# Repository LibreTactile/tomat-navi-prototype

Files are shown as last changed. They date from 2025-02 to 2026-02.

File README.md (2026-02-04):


# tomat-navi-prototype
Prototype for Touch Matrix Assistive Technology Navigator (TOMAT) 

# Overview
“Touch Matrix Assistive Technology Navigator” (tomat navigator) is an affordable, open-source assistive technology that uses AI and tactile technologies to make it easier and more natural for visually impaired users to navigate the internet. It works as a companion device for screen readers, providing an interactive non-visual representation of a webpage through audio-tactile feedback. It works as a companion device for screen readers, providing an interactive non-visual representation of a webpage through audio-tactile feedback. It was codesigned with and for visually impaired screen reader users. 

## TOMAT Light (Smartphone Version)
A software-only alternative called **TOMAT Light** is available as a Progressive Web App (PWA). It uses a smartphone's touchscreen and vibration motor to simulate the hardware interface.
- **Repository**: [tomat-light-pwa](https://github.com/LibreTactile/tomat-light-pwa)
- **Design**: Leveraging WebRTC for peer-to-peer connection with the browser extension.

# Repo structure
- docs
    - [prototype description](/docs/1%20prototype%20description.md)
        - [design document draft](/docs/2%20design%20doc.md)
    - [use guide](/docs/3%20use%20guide.md)
    - [build guide](/docs/4%20build-guide.md) (pending)

- source files
    - hardware (alternative use the tomat-[light-launcher](https://github.com/LibreTactile/light-launcher))
      - 3d printer files (freeCAD 3d models) 
      - pico firmware
      - bill of materials (for building 5 prototypes)
    - software
      - chrome extension
    - external repositories
      - [tomat-light-pwa](https://github.com/LibreTactile/tomat-light-pwa) (TOMAT Light Smartphone Interface)

# Intellectual Property Strategy

## Commitment to Open Innovation with Strategic Protection

Our team remains commited to our mission to advance assistive technology through open collaboration. To balance innovation protection with community growth, we've implemented a **phased intellectual property strategy** guided by [Axelys](https://www.axelys.ca/en/), Quebec's nonprofit expert in research commercialization and technology transfer.

### Current Licensing Framework (Phase 1)


**Temporary License:** Creative Commons Attribution-NonCommercial-ShareAlike 4.0 International  

**Key Provisions:**
- ✅ **Permitted:**  
  - Academic research & non-commercial use  
  - Prototyping & personal adaptation  
  - Educational implementations  

- ⚠️ **Restricted Without Written Consent:**  
  - Commercial distribution or integration  
  - Forking for proprietary development  
  - Patent filings derived from this work  

**Full License Text:** [LICENSE](/LICENSE)

> External contributions will require CLA to facilitate relicensing. 

### Transition Roadmap to Full Open Source (Phase 2)

**Target License:** CERN-OHL-P v2 or Apache 2.0 (or equivalent)  

**Transition Triggers:**  
1. Completion of Axelys' technology assessment (AXE-0431: completed on summer 2024)
2. Establishment of sustainable funding model (ongoing)

**Declaration of intention:** All core contributors have declared their intention to open-source release through our [Open Source Release Agreement](/docs/open-source%20release%20agreement.pdf).

### Why This Approach?

1. **Protection During Development**  
   Prevents patent trolling while enabling academic collaboration during critical R&D phases.

2. **Sustainable Commercialization**  
   Allows time to establish ethical commercialization partnerships that will fund ongoing development.

3. **Community Safeguards**  
   Ensures derivative works remain accessible to visually impaired users through copyleft provisions.

### How This Affects You

**Researchers & Educators:**  
- Full access to current implementations  
- Ability to publish papers/case studies (with attribution)  
- Pathway for collaborative grants  

**Developers:**  
- Protected right to fork upon full open-source release  
- Clear timeline for commercial participation  

**End Users:**  
- Guaranteed perpetual access to assistive innovations  
- Protection from proprietary lock-in  

*This strategy follows OSI's [Delayed Open Source Publication Guidelines](https://opensource.org/delayed-open-source-publication)*

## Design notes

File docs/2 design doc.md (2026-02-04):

# **TOMAT Navigator Design Document**  
**A Multimodal, Non-Linear Web Navigation System for Visually Impaired Users**  

version: 0.1,draft for prototype for codesing and usability evaluation  
author: Juan Nino  
date: 24 February 2025

## **Context**  

>[Related publication](https://digitalcommons.lindenwood.edu/faculty-research-papers/714/)  
Nino, J., Ochoa, S., Kiss, J., Edwards, G., Morales, E., Hutson, J., ... & Wittich, W. (2024). Assistive Technologies for Internet Navigation: A Review of Screen Reader Solutions for the Blind and Visually Impaired. International Journal of Recent Engineering Science, 11(6).

The **TOMAT Navigator** is a hardware and software **assistive human-computer interface** within the **LibreTactile** ecosystem (vision: *touching ideas*), designed to empower visually impaired users to navigate the internet through **nonlinear, multimodal interaction**. Traditional screen readers present content sequentially, forcing users to reconstruct webpage structure mentally. TOMAT addresses this by generating multimodal **interactable models** of webpages, enabling users to explore relationships between elements, adjust detail granularity, and interact contextually via audio-tactile feedback and gesture-based inputs. Algorithms and AI systems generate interactive webpage models from the DOM, representing structural (hierarchical), visuospatial, and/or semantic relationships. Alternatively, models for popular pages could be shared by community of users and developers. 

TOMAT Navigator transforms linear screen reader experiences into **multiscale, nonlinear navigation**. It dynamically models webpage structure as a **collapsible tree**, allowing users to "zoom in & out" between high-level overviews and granular details. Key innovations include:  
- **Multiperspective Modeling**: Represent webpages as information graphs that can be organized into multiple tree hierarchies, such as tables of contents. These hierarchies are shaped by the type of nonlinear information used to build them, including semantic ontologies, hierarchical relationships, or visuospatial layouts.
- **Multiscale Rendering**: Enable interaction with content through the generated table of contents, offering multiple levels of abstraction (e.g., from section summaries to full text).
- **AI Assistant**: Automatically annotate pages, predict navigation paths, and fix accessibility issues while allowing manual user control.  
- **Contextual Interactions**: Intuitive touch/button interactions to switch modes, adjust detail, or trigger actions.  

**Hardware Overview**:  
The TOMAT hardware module is a portable, 3D-printed tactile interface featuring:  
- A **4x4 vibratory matrix** to represent webpage elements through tactile "table of contents".  
- **Gesture-enabled buttons** (8 total) supporting taps, holds, and combos for contextual actions.  
- **Raspberry Pi Pico microcontroller** for real-time communication with the software module via USB/WiFi.  
- Ergonomic design (12cm x 8cm) with rounded edges for comfortable handheld use.  

---

## **Core Features**  

### **1. Multiperspective Modeling**  
- **Dynamic Graph/Tree Generation**: Extract relationships between DOM elements (headings, links, tables) and represent them as interactive tree hierarchies (e.g., tables of contents).  
- **Custom Ontologies**: Users or communities define semantic relationships (e.g., `#workflow`, `#socialnetworking`) to tailor generated webpage models.  

### **2. Multiscale Rendering (Levels of Detail)**  
- **Granularity Control**:  
  - **Zoom In/Out**: Adjust detail with `+/-` buttons (e.g., show all subheadings vs. top-level headings).  
  - **Auto-Summarization**: AI generates concise section summaries, enabling quick overviews. User can then manually dive deeper into the details of a section of interest.  
- **Adaptive Focus**:  
  - **Element Exploration Mode**: Interact with complex elements (e.g., tables, lists) using the full tactile matrix.  
  - **Type Grouping**: Group elements by type (e.g., links in one column) for focused navigation.  

### **3. AI Assistant & Automation**  
- **Pre-Annotation**:  
  - AI labels elements (e.g., "navigation menu," "article body") where human annotations are missing.  
  - Override AI suggestions manually (e.g., relabel, hide elements).  
- **Task Automation**:  
  - **Smart Navigation**: Predict frequent paths (e.g., "Skip to main content") based on user habits.  
  - **Accessibility Fixes**: Auto-correct ARIA roles or missing alt-text, pending user approval.  
- **Interruptible Workflow**: Pause/reset AI actions instantly via gestures (e.g., double-tap to halt automation).  

### **4. Contextual Interaction & Gestures**  
- **Gesture Library**:  
  | **Button/Gesture**       | **Action**                                  |  
  |---------------------------|--------------------------------------------|  
  | `Single Tap (T)`          | Read element description.                  |  
  | `Double Tap (TT)`         | Jump to element.                           |  
  | `Press & Hold (PH)`       | Save to favorites.                         |  
  | `Tap + Hold (TPH)`        | Trigger AI summary or custom script.       |  
- **Mode Switching**:  
  - Cycle through **Basic**, **Favorite**, and **Changes** modes with the `Star` button.  
  - **Interactive Help Mode**: On-demand tutorials for gestures and features.  

### **5. Accessibility & Customization**  
- **Hardware Flexibility**:  
  - Modular 3D-printed tactile matrix (4x4 grid) with adjustable vibration intensity.  
  - Open-source CAD files for community-driven hardware variants (e.g., larger matrices).  
- **Software Personalization**:  
  - Adjust speech rate, AI verbosity, and gesture sensitivity.  
  - Map gestures to plugins (e.g., `TPH` triggers a Python script for note-taking).  

### **6. Community & Plugin Ecosystems**  
- **Plugin Marketplace**:  
  - Review and download community-built tools: AI models (e.g., "e-commerce navigation expert"), gesture packs, or ontologies.  
  - Share custom plugins (e.g., Wikipedia-focused summarizers).  
- **Collaborative Resources**:  
  - Access and contribute to community resources.  
- **Hardware Customization**:  
  - Community-designed 3D-printed cases, alternative button layouts, or Bluetooth/WiFi modules.  

---

### **Simple User**  
- *“I want to navigate a news site without getting lost in menus. With TOMAT, I collapse the page to headings only, zoom into the ‘Sports’ section, and let AI provide  a quick overview of the article.”*  
- **Key Actions**:  
  - Use `#headings` perspective to skip irrelevant content.  
  - Double-tap `+` to expand the "Sports" subsection.  
  - Enable `AI Summary` .  

### **Advanced User**  
- *“I need to analyze research papers daily. I use TOMAT’s AI to pre-tag tables, then override labels for custom workflows.”*  
- **Key Actions**:  
  - Train AI to recognize academic paper structures.  
  - Use `Type Grouping` to isolate tables/figures.  
  - Integrate TOMAT with note-taking apps and export graphs/models. 

---

## **Technical Architecture**  

### **System Design**  
- **Model-View-Controller (MVC)**:  
  - **Model**: Hierarchical webpage graph (JSON-LD/HTML).  
  - **View**: Cross-platform UI (Android, screen reader, browser extension, tactile matrix).  
  - **Controller**: Gesture interpreter & AI assistant.  
- **Data Flow**:  
  1. Browser extension extracts DOM → builds graph.  
  2. AI annotates/optimizes graph → sends to hardware.  
  3. User interacts via gestures → updates model in real time.  

### **Hardware Specifications**  
- **Tactile Matrix**: 4x4 grid with vibration motors (spatial encoding of elements).  
- **Microcontroller**: Raspberry Pi Pico (WebSerial/USB HID).  
- **Connectivity**: USB-C, WiFi/Bluetooth (future iterations).  

### **AI/ML Integration**  
- **Models**:  
  - **Open Source LLM**: For text summarization and label prediction.  
  - **Accessibility Validator**: Flags ARIA/HTML5 compliance issues.  
- **Community Training**: Users contribute anonymized data to improve AI accuracy.  

---

## **Future Integrations**  
- **Annotation Studio**: Export TOMAT graphs for collaborative editing and note-taking.  
- **Plugin Marketplace**: Download community plugins, AI models, and hardware blueprints.  

> Note: not all features will be implemented on the first prototype, and other hardware implementations will be released as derivative in the future. 

---

# TOMAT Light Design Document

## 1. Introduction
TOMAT Light is a smartphone alternative to the TOMAT hardware device (a "remote control" for the internet). It replicates TOMAT's core functionality while eliminating hardware barriers (cost, distribution, maintenance) by leveraging smartphones and web technologies.

**Key Advantage:**
Instant distribution via Progressive Web App (PWA), no app stores required.

## 2. User Needs
**Core Requirements:**
* Real-time pairing with the TOMAT Navigator Chrome extension.
* Screen-based simulation of TOMAT's interface:
    * **Output:** Haptic feedback (vibration matrix).
    * **Input:** Touchscreen buttons.
* Tactile feedback emulating physical components:
    * **Haptic pulse:** Short 50ms pulse on every button press.
    * **Haptic states:**
        * `INACTIVE`: Gray appearance, no feedback.
        * `ACTIVE`: Green appearance, continuous vibration.
        * `PULSATING`: Red appearance, rhythmic pulses.
* Screen-reader compatibility for accessibility.

## 3. System Overview
**Architecture:**
The system follows a peer-to-peer architecture where:
* **PWA** acts as the "Interface" role
* **Chrome Extension** acts as the "Navigator" role
* **Firebase Firestore** serves strictly as a signaling broker (not a data relay)
Once the WebRTC connection is established, all communication flows directly between peers without server intermediation.

**Components:**
1. TOMAT Light PWA (smartphone app)
2. TOMAT Navigator Chrome extension
3. Firebase Firestore signaling infrastructure

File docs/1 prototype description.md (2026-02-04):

# Touch Matrix Assistive Technology Navigator (TOMAT)
TOMAT (Touch Matrix Assistive Technology Navigator) is a versatile system that helps visually impaired users navigate the web more effectively. It complements traditional screen readers with an interactive, non-visual way to explore web content using touch, sound, and context-aware feedback. By combining a physical interface with audio-tactile cues, TOMAT makes it easier to understand complex websites. Its modular, open design allows for customization and ongoing improvements, ensuring it meets the unique needs of its users.

## System Architecture
**Hardware Module**  
The hardware module provides tactile and auditory feedback, allowing users to interact with web content intuitively and nonlinearly. Key features include:

* Compact Design: Ergonomic, 12x8x2 cm with rounded corners.
* Tactile Feedback: A 4x4 grid of vibration points, each representing webpage elements (e.g., headings, links). Patterns indicate element type and state.
* Interaction Buttons: Row-specific buttons for contextual actions (e.g., read, save) and control buttons for navigation, mode switching, and granularity adjustment.
* Gesture Support: Buttons recognize four gestures—tap, double tap, press-and-hold, and tap-hold—for various functions.
* Powered by Raspberry Pi Pico: Drives vibration motors and communicates with the software via WebSerial USB, with potential for wireless protocols in the future.
* Customizable 3D-Printed Enclosure: Affordable and easy to modify.

**TOMAT Light (Smartphone Alternative)**
[TOMAT Light](https://github.com/LibreTactile/tomat-light-pwa) is a smartphone-based alternative to the physical hardware. It is a Progressive Web App (PWA) that turns a smartphone screen into a tactile interface, replicating the core functionality of the physical device.
* **Instant Access**: No hardware assembly required; runs in a web browser.
* **Haptic Feedback**: Uses the smartphone's vibration motor to simulate tactile feedback (pulses and patterns).
* **Touch Interface**: Simulates the 4x4 grid and button layout on the touchscreen.
* **Connectivity**: Connects to the browser extension via WebRTC Peer-to-Peer.

**Software Module**  
The software module powers the hardware interface, managing webpage content extraction, navigation, and tactile feedback. Key features include:

* Browser Extension: Extracts webpage elements (e.g., headings, links, images) to build a customizable, hierarchical page model.
* Personalized Navigation: Users can zoom between overviews and details, collapsing or expanding elements to match their preferences. Different modes highlight semantic, structural, or visuospatial relationships.
* Tactile Feedback Translation: Converts the webpage model into spatially encoded vibrations on the hardware, with distinct patterns for different element types.
* Operation Modes: Includes Basic (all elements), Favorite (user-selected), and Changes (recent updates). Special modes like Interactive Help and Element Exploration focus on specific elements or provide guided navigation.
* Future-Ready Design: Supports AI-driven features, task automation, cross-platform compatibility, and community-driven development for continuous improvement and broader accessibility.

---

## Key Features of Webpage Navigation

- **Navigating Webpage Elements**:  
  - Elements are grouped into "windows" (sets of four) displayed on the tactile grid.  
  - **Up/Down Buttons** allow users to scroll through windows or jump across multiple windows using gestures like taps or press-and-hold actions.  

- **Cursor and Feedback**:  
  - A pulsing vibration shows the cursor's position, while other elements provide constant feedback. The device automatically adjusts to keep the cursor visible.  

- **Interacting with Elements**:  
  - **Row Buttons** let users read, navigate to, save, or perform actions (e.g., summarization) on individual elements.  
  - **Next/Previous Buttons** allow element-by-element navigation or jumps between different types (e.g., headings to links).  

- **Detail Level Control**:  
  - Adjust granularity using **Plus/Minus Buttons** to show fewer or more details, group elements by type, or explore individual elements in-depth.  

- **Operation Modes**:  
  - **Basic Mode**: All elements.  
  - **Favorite Mode**: User-selected elements.  
  - **Changes Mode**: Highlights updates since the last visit.  
  - Special modes like **Interactive Help** or **Element Exploration** provide tailored views or guidance.  

- **Offline Exploration**:  
  - Navigate pre-downloaded content (e.g., Wikipedia articles) without internet, maintaining full tactile and feedback functionality.  

- **Customizable Settings**:  
  - Adjust vibration, verbosity, or speech rate during use for a personalized experience.

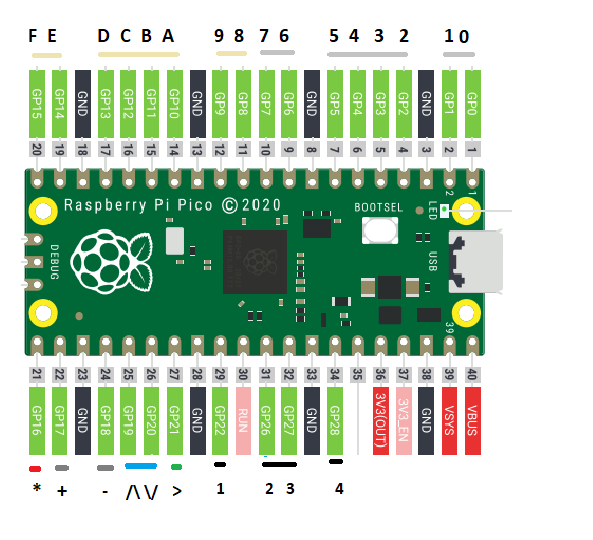
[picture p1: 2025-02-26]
src/hardware/pico firmware/Pin definitions.png

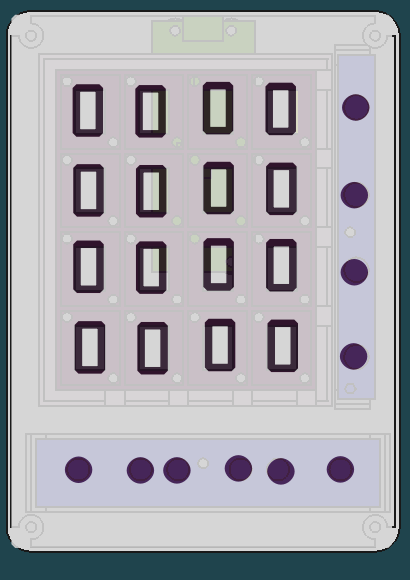
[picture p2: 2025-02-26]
src/hardware/alignment .png

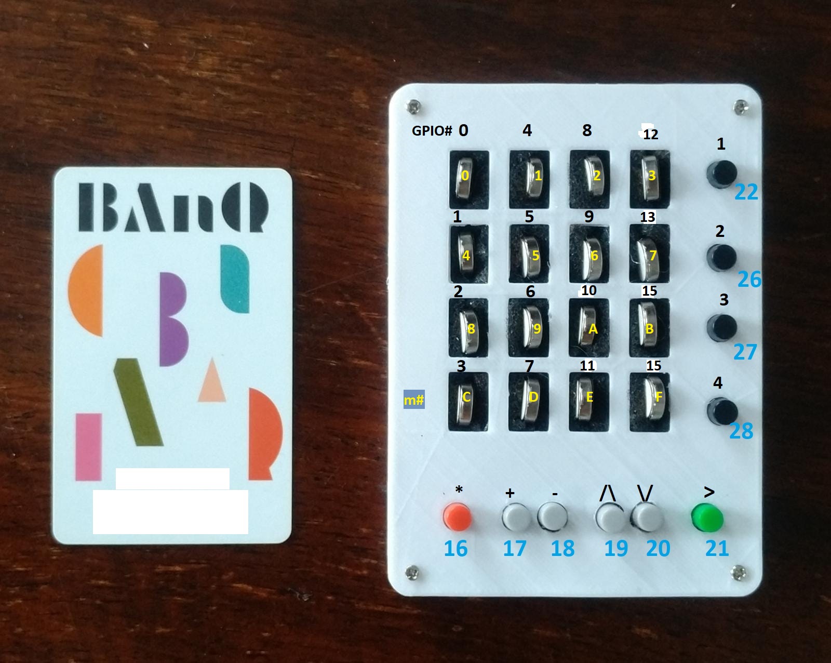
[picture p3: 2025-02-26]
src/hardware/pico firmware/MVP pin definitions.jpeg

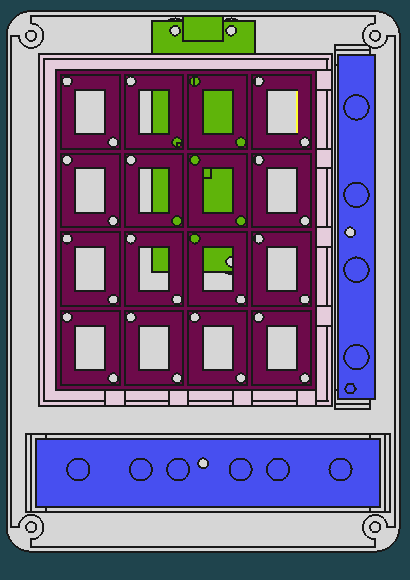
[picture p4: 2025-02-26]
src/hardware/alignment2.png

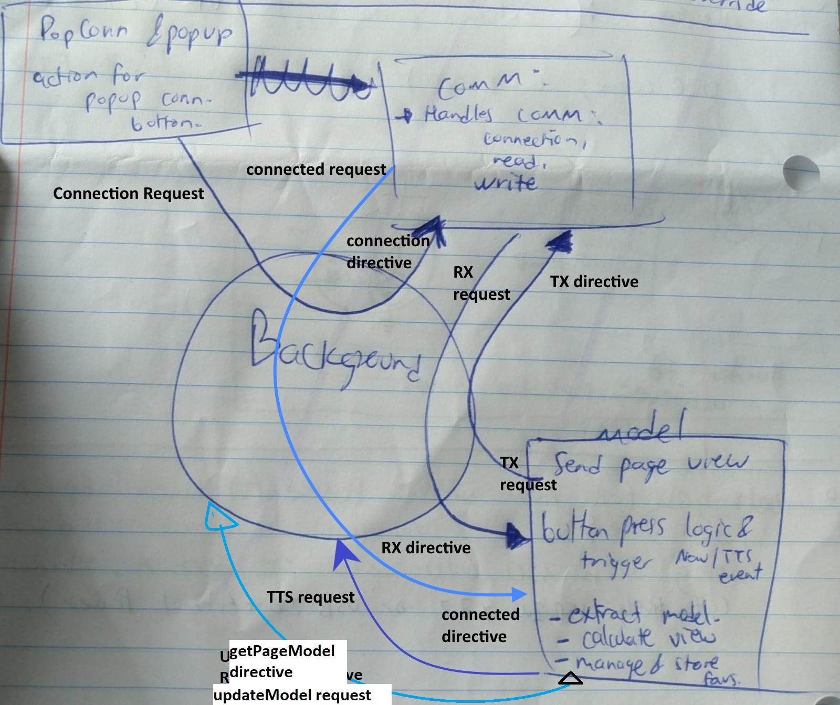
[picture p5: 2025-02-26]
src/software/software_arch.jpeg

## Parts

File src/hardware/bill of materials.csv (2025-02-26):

Product | Price | Quantity | Total amount | Supplier | Justification | Link
Heat shrinks | $16.95 | 1.00 | $16.95 | amazon | Sealing solder connections | https://www.amazon.ca/gp/product/B07MTTXJKR/ref=ox_sc_act_title_1?smid=A18KQ287CBMN7O&psc=1
M2 nuts and bolts | $16.27 | 1.00 | $16.27 | amazon | Fastening components. | https://www.amazon.ca/Hilitchi-600-Piece-Phillips-Assortment-stainless/dp/B01N2XYON0?rnid=3276483011&rps=1
Button caps | $22.20 | 1.00 | $22.20 | amazon | Requested by participants | https://www.amazon.ca/gp/product/B07CMZCQS5/ref=ox_sc_act_title_1?smid=A3AX24NME6J6T3&psc=1
Vibrator Motors | $28.67 | 4.00 | $114.68 | amazon | Simplification of tactile actuator | https://www.amazon.ca/gp/product/B07Q1ZV4MJ/ref=ox_sc_act_title_1?smid=A73Y9IWAXYJB2&psc=1
Diodes | $6.99 | 1.00 | $6.99 | amazon | FEM protection | https://www.amazon.ca/dp/B07RFSXZW7?ref_=cm_sw_r_cp_ud_dp_V5AZBPGNAV28X00757CB
Driver ULN 2003 | $17.99 | 1.00 | $17.99 | amazon | Multiplexer uC interface | https://www.amazon.ca/gp/product/B07S2LYQLB/ref=ox_sc_act_title_3?smid=A3MM3IVRRE6BVX&psc=1
Analog IC's | $29.90 | 1.00 | $29.90 | amazon | Multiplexer uC interface | https://www.amazon.ca/gp/product/B07V1PKDZS/ref=ox_sc_act_title_1?smid=A2P3VRURQXZ6E2&psc=1
Raspberry pi pico | $12.99 | 4.00 | $51.96 | amazon | Open source microcontroller | https://www.amazon.ca/gp/product/B08TQSDP28/ref=ox_sc_act_title_1?smid=A1YP59NGBNBZUR&psc=1

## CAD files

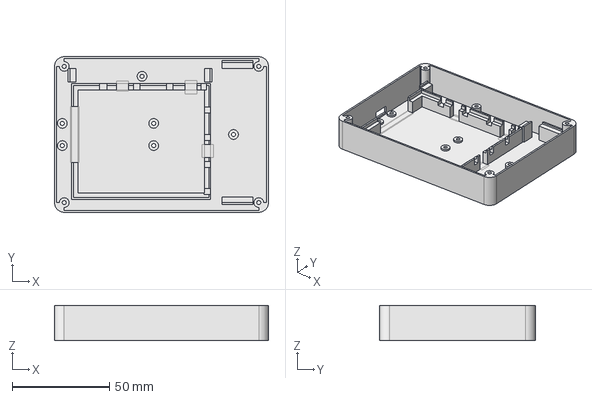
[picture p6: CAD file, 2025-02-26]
src/hardware/3d print files/TOMAT v0.5 CASE/tnavComplete_newCaseNholes.FCStd
110.0 x 80.0 x 18.0 mm

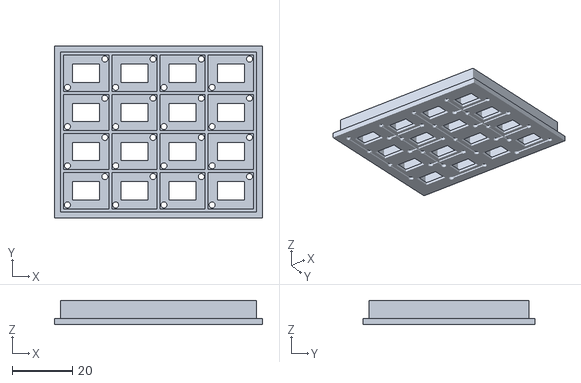
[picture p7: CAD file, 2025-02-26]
src/hardware/3d print files/TOMAT v0.5 4x4MATRIX CASE/tactileNav3_4x4_v2-Case-stl.stl
69.0 x 57.0 x 8.00

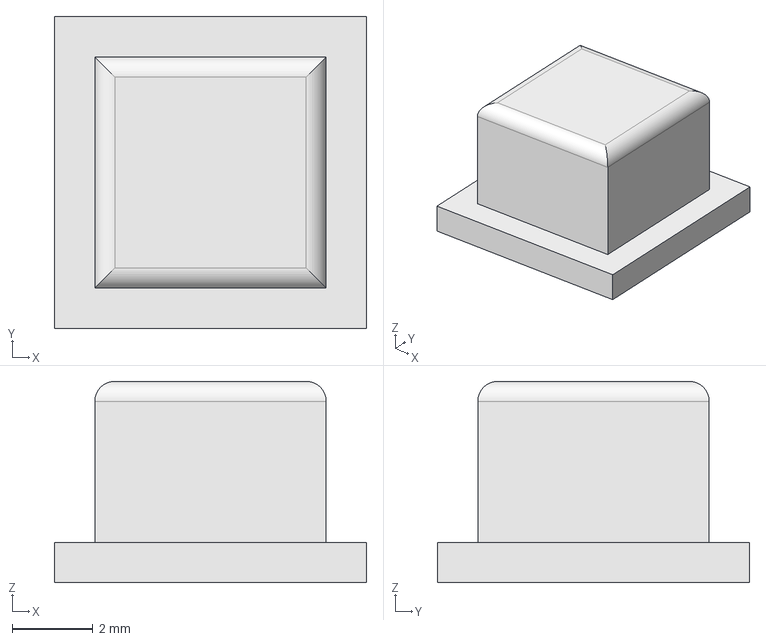
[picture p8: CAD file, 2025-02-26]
src/hardware/3d print files/TOMAT v0.5 BUTTONS/btnCap1_correct_5mmbtn.FCStd
7.75 x 7.75 x 5.00 mm

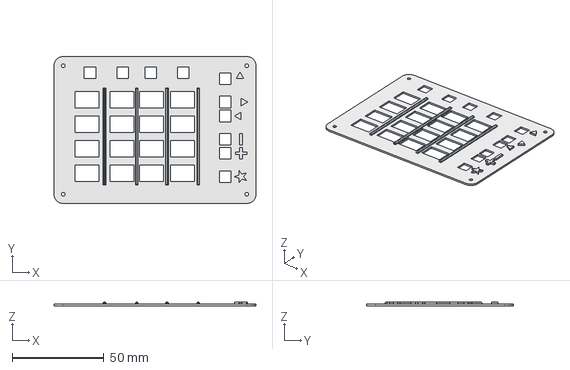
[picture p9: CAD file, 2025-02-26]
src/hardware/3d print files/TOMAT v0.5 LID/tnavC5 lid _ relief_ final.FCStd
110.0 x 80.0 x 2.00 mm

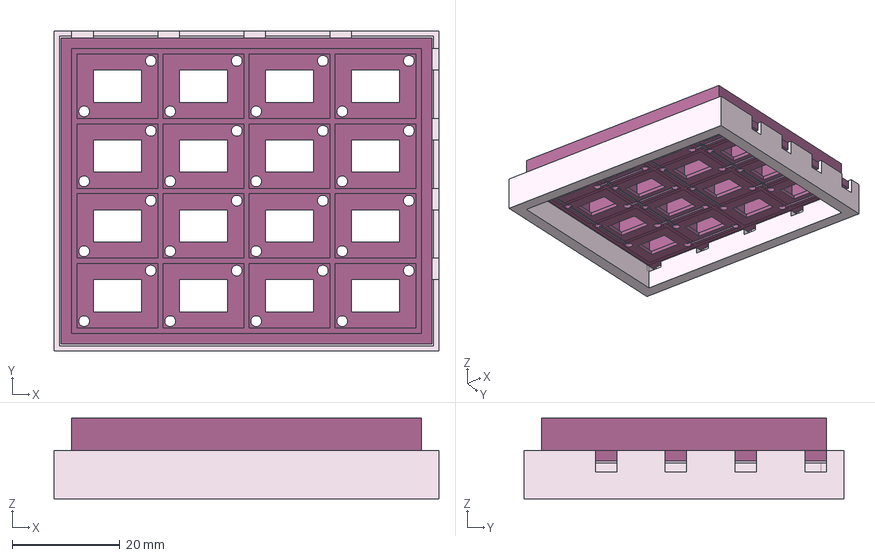
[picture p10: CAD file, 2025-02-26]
src/hardware/3d print files/TOMAT v0.5 4x4MATRIX CASE/FINAL_4x4matrix.FCStd
71.6 x 59.6 x 15.0 mm
Case
Support

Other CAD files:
src/hardware/3d print files/TOMAT v0.5 CASE/tnavC2_newCaseNholes-tnav Case.stl
src/hardware/3d print files/TOMAT v0.5 BUTTONS/btnCap1_correct_5mmbtn-Body.stl
src/hardware/3d print files/TOMAT v0.5 LID/tnavC5 lid _ relief_ final-tnav LID.stl

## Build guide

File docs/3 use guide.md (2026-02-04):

# 1 Setup

- **Hardware Setup**: Plug-in usb cable to computer and tomat navi device. No driver needs to be installed.
- **TOMAT Light (Smartphone) Setup**: Open the TOMAT Light PWA on your smartphone. (URL: https://libretactile.github.io/tomat-light-pwa/)
- Install chrome extension  
  - Unzip `tomat navi 1.0 browser extension.zip`.  
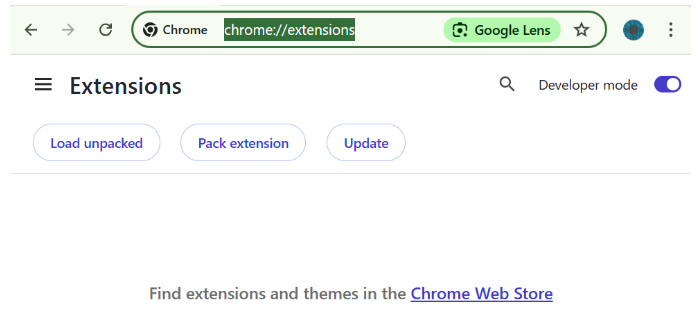
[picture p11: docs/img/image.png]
  - Go to `` chrome://extensions/` `` on google chrome and enable the `developer mode` toggle on the top right  
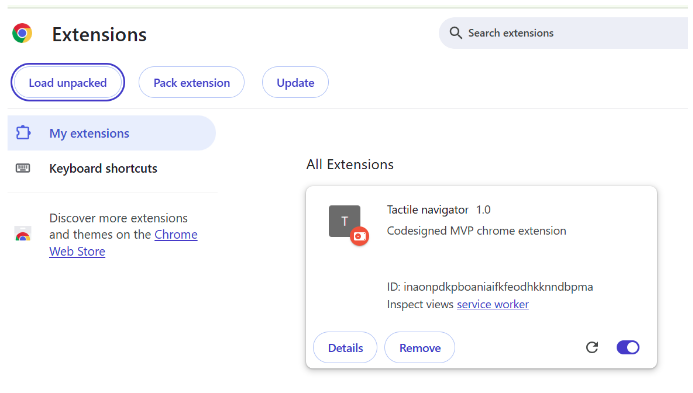
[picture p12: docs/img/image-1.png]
  - Click on `Load unpacked` and select the folder that was just unzipped.  
  - (optional) install/configure your screen reader software, we recommend the open-source [NVDA](https://www.nvaccess.org/download/) screen reader software. 

# 2 Start 

- Run the extension by clicking on the extension icon, or using the keyboard shortcut `ctrl + shift + q` .   
- Click connect to show available devices.
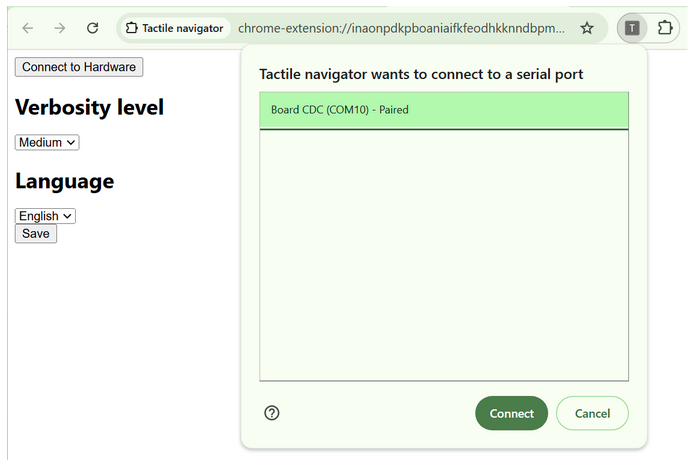
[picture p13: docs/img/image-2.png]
Connect to device
  - **For Hardware**: Choose the `board CDC` device. 
  - **For TOMAT Light**: Choose `WebRTC` as the connection type. Ensure both your computer and smartphone are on the same network (public IP) for easy discovery.
- (optional) change extension verbosity level and language, then hit on `save` to store your settings across sessions. 

# 3 Usage example

- You are ready to navigate. Just open a tab and start navigating the webpage with tomat navigator, as soon as you switch tabs the extension will create a model of the page and send it to the interface for interaction.   
- Basic controls:  
  - Tapping next (right arrow) button will take you to the next element of the page.  
  - Tap row button reads the element content (according to verbosity setting)  
  - Double tapping row button will scroll/navigate to that element  
  - Press and hold row button would add to favorites for that page (persistent across sessions)  
  - Tapping star will cycle through the presentation modes (normal, favorites, help mode).   
  - Tapping \+ or \- will show more or less details in the interface (headings level 1 only, vs heading level 1,2,3 and links).   
  - Tapping up or down will move the part of the webpage that is display in the tactile matrix.   
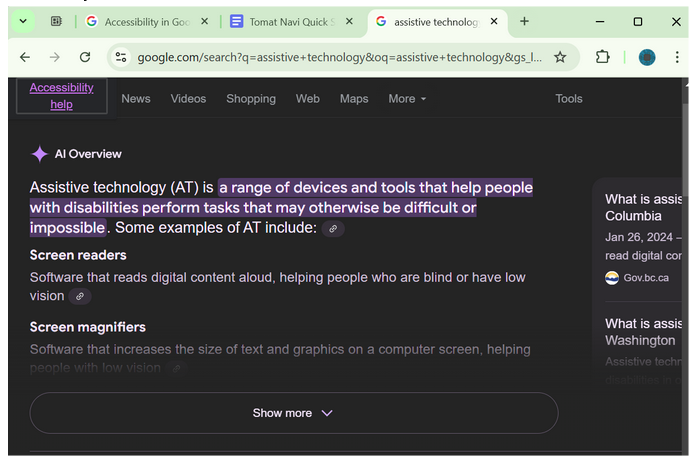
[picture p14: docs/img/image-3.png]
Accessibility links example
- For example: searching for “assistive technology” in a new tab will present the (invisible) accessibility links in the tactile interface. 

# 4 Troubleshooting

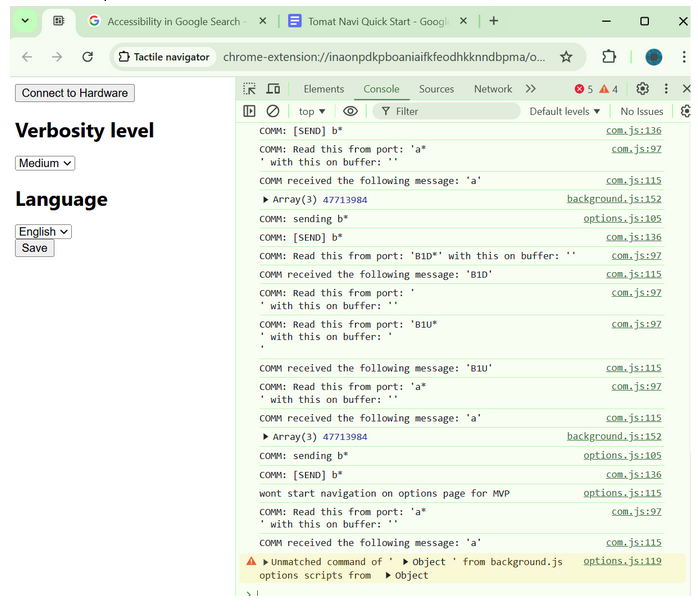
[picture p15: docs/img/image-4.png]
Chrome extension console
- You can show the console on the chrome extension (`ctrl + shift + i`) to review the system log, including what pages it has read, modeled and sent to the device, as well as what buttons the device has reported. 

# 5 Extended use guide
... under construction

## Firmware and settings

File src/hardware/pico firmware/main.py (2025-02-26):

#configuration variables
delayOff= 00.001
DELAY_ON=0.001
pulseTimer=0
PULSE_DURATION=0.12
keepAliveTimer=0
KEEP_ALIVE_PERIOD=10
pulse=False


# IO SECTION written by Juan Nino - Sept 2022
# TOMAT NAVI V0.5.1
# ----------START OF USB SERIAL SECTION----------------------
# USB SERIAL SECTION Copied from raspberry pi forums: https://forums.raspberrypi.com/viewtopic.php?t=302889 July 2022
# USB serial communication for the Raspberry Pi Pico (RD2040) using the second RD2040
# thread/processor (written by Dorian Wiskow - Janaury 2021)

from sys import stdin, exit
from _thread import start_new_thread
from utime import sleep
from machine import Pin




# 
# global variables to share between both threads/processors
# 
bufferSize = 1024                 # size of circular buffer to allocate
buffer = [' '] * bufferSize       # circuolar incomming USB serial data buffer (pre fill)
bufferEcho = False                 # USB serial port echo incooming characters (True/False) 
bufferNextIn, bufferNextOut = 0,0 # pointers to next in/out character in circualr buffer
terminateThread = False           # tell 'bufferSTDIN' function to terminate (True/False)


#
# Interface pinout definitions:
# Buttons
bStar = Pin(16, Pin.IN, Pin.PULL_UP)
bPlus = Pin(17, Pin.IN, Pin.PULL_UP)
bMin = Pin(18, Pin.IN, Pin.PULL_UP)
bUp = Pin(19, Pin.IN, Pin.PULL_UP)
bDown = Pin(20, Pin.IN, Pin.PULL_UP)
bNext = Pin(21, Pin.IN, Pin.PULL_UP)

b1 = Pin(22, Pin.IN, Pin.PULL_UP)
b2 = Pin(26, Pin.IN, Pin.PULL_UP)
b3 = Pin(27, Pin.IN, Pin.PULL_UP)
b4= Pin(28, Pin.IN, Pin.PULL_UP)
# Motors
m0 = Pin(0,Pin.OUT)
m1 = Pin(4,Pin.OUT)
m2 = Pin(8,Pin.OUT)
m3 = Pin(12,Pin.OUT)
m4 = Pin(1,Pin.OUT)
m5 = Pin(5,Pin.OUT)
m6 = Pin(9,Pin.OUT)
m7 = Pin(13,Pin.OUT)
m8 = Pin(2,Pin.OUT)
m9 = Pin(6,Pin.OUT)
mA = Pin(10,Pin.OUT)
mB = Pin(15,Pin.OUT)
mC = Pin(3,Pin.OUT)
mD = Pin(7,Pin.OUT)
mE = Pin(11,Pin.OUT)
mF = Pin(10,Pin.OUT)

#led1 = Pin(25, Pin.OUT) #led

#arrays
motors= [m0, m1, m2, m3, m4, m5, m6, m7, m8, m9, mA, mB, mC, mD, mE, mF]
mBuffer= [0,0,0,0,0,0,0,0,0,0,0,0,0,0,0,0] 
interfaceButtons= [1,1,1,1,1,1,1,1,1,1]
pulsatingMotor= -1


#
# bufferSTDIN() function to execute in parallel on second Pico RD2040 thread/processor
#
def bufferSTDIN():
    global buffer, bufferSize, bufferEcho, bufferNextIn, terminateThread
    
    while True:                                 # endless loop
        if terminateThread:                     # if requested by main thread ...
            break                               #    ... exit loop
        buffer[bufferNextIn] = stdin.read(1)    # wait for/store next byte from USB serial
        if bufferEcho:                          # if echo is True ...
            print(buffer[bufferNextIn], end='') #    ... output byte to USB serial
        bufferNextIn += 1                       # bump pointer
        if bufferNextIn == bufferSize:          # ... and wrap, if necessary
            bufferNextIn = 0


#
# function to check if a byte is available in the buffer and if so, return it
#
def getByteBuffer():
    global buffer, bufferSize, bufferNextOut, bufferNextIn
    
    if bufferNextOut == bufferNextIn:           # if no unclaimed byte in buffer ...
        return ''                               #    ... return a null string
    n = bufferNextOut                           # save current pointer
    bufferNextOut += 1                          # bump pointer
    if bufferNextOut == bufferSize:             #    ... wrap, if necessary
        bufferNextOut = 0
    return (buffer[n])                          # return byte from buffer

#
# function to check if a line is available in the buffer and if so return it
# otherwise return a null string
#
# NOTE 1: a line is one or more bytes with the last byte being LF (\x0a)
#      2: a line containing only a single LF byte will also return a null string
#
def getLineBuffer():
    global buffer, bufferSize, bufferNextOut, bufferNextIn

    if bufferNextOut == bufferNextIn:           # if no unclaimed byte in buffer ...
        return ''                               #    ... RETURN a null string

    n = bufferNextOut                           # search for a LF in unclaimed bytes
    while n != bufferNextIn:
        if buffer[n] == '\x0a':                 # if a LF found ... 
            break                               #    ... exit loop ('n' pointing to LF)
        n += 1                                  # bump pointer
        if n == bufferSize:                     #    ... wrap, if necessary
            n = 0
    if (n == bufferNextIn):                     # if no LF found ...
            return ''                           #    ... RETURN a null string

    line = ''                                   # LF found in unclaimed bytes at pointer 'n'
    n += 1                                      # bump pointer past LF
    if n == bufferSize:                         #    ... wrap, if necessary
        n = 0

    while bufferNextOut != n:                   # BUILD line to RETURN until LF pointer 'n' hit
        
        if buffer[bufferNextOut] == '\x0d':     # if byte is CR
            bufferNextOut += 1                  #    bump pointer
            if bufferNextOut == bufferSize:     #    ... wrap, if necessary
                bufferNextOut = 0
            continue                            #    ignore (strip) any CR (\x0d) bytes
        
        if buffer[bufferNextOut] == '\x0a':     # if current byte is LF ...
            bufferNextOut += 1                  #    bump pointer
            if bufferNextOut == bufferSize:     #    ... wrap, if necessary
                bufferNextOut = 0
            break                               #    and exit loop, ignoring (i.e. strip) LF byte
        line = line + buffer[bufferNextOut]     # add byte to line
        bufferNextOut += 1                      # bump pointer
        if bufferNextOut == bufferSize:         #    wrap, if necessary
            bufferNextOut = 0
    return line                                 # RETURN unclaimed line of input

#
# main program begins here ...
#
# set 'inputOption' to either  one byte ‘BYTE’  OR one line ‘LINE’ at a time. Remember, ‘bufferEcho’
# determines if the background buffering function ‘bufferSTDIN’ should automatically echo each
# byte it receives from the USB serial port or not (useful when operating in line mode when the
# host computer is running a serial terminal program)
#
# start this MicroPython code running (exit Thonny with code still running) and then start a
# serial terminal program (e.g. putty, minicom or screen) on the host computer and connect
# to the Raspberry Pi Pico ...
#
#    ... start typing text and hit return.
#
#    NOTE: use Ctrl-C, Ctrl-C, Ctrl-D then Ctrl-B on in the host computer terminal program 
#           to terminate the MicroPython code running on the Pico 
#

# -------------------------- END OF USB SERIAL SECTION-----------------------------------

def clear_all():
    m0.value(0)
    m1.value(0)
    m2.value(0)
    m3.value(0)
    m4.value(0)
    m5.value(0)
    m6.value(0)
    m7.value(0)
    m8.value(0)
    m9.value(0)
    mA.value(0)
    mB.value(0)
    mC.value(0)
    mD.value(0)
    mE.value(0)
    mF.value(0)
    

def set_window(line):
    global pulsatingMotor
    global mBuffer
    
   
    #line = '1,2,3,4P*'
    #get only info before termination character
    tline= line.split('*')[0]
    
    motorValues= tline.split(',') #get one value per display line
    #motorValues= [1,2,3,4P]

    #make sure string values are ok
    for val in motorValues:
        if(len(val)>0):
            if(val[0]<"0" or val[0]>"4"):
                return
        else:
            return



    mBuffer=  [0,0,0,0,0,0,0,0,0,0,0,0,0,0,0,0] 
    clear_all()
    
    l = 0
    pulsating=False
    pulsatingMotor=-1
    for val in motorValues: #for each line rx
        #val = 1 // 2P // 3 // 4
        
        #first line
        if (l==0):
            
            if(len(val)>1):         # if there is a char after the column number, then pulsating
                pulsating=True      # this will be a pulsating motor
            if(val[0]=="1"):        # did we receive this motor number?
                mBuffer[0]=1         # turn on the first motor on this row
                if(pulsating):      # are you searching for a pulsating motor?
                    pulsatingMotor= 0  # set this to be a pulsasting motor
                    pulsating=False # disable search for pulsating motor
            elif (val[0]=="2"):
                 mBuffer[1]=1
                 if(pulsating):
                    pulsatingMotor= 1
                    pulsating=False
            elif (val[0]=="3"):
                 mBuffer[2]=1
                 if(pulsating):
                    pulsatingMotor= 2
                    pulsating=False
            elif (val[0]=="4"):
                 mBuffer[3]=1 
                 if(pulsating):
                    pulsatingMotor= 3
                    pulsating=False
        # second line
        if (l==1):
            if(len(val)>1):
                pulsating=True
            if(val[0]=="1"):
                mBuffer[4]=1
                if(pulsating):
                    pulsatingMotor= 4
                    pulsating=False
            elif (val[0]=="2"):
                 mBuffer[5]=1
                 if(pulsating):
                    pulsatingMotor= 5
                    pulsating=False
            elif (val[0]=="3"):
                 mBuffer[6]=1
                 if(pulsating):
                    pulsatingMotor= 6
                    pulsating=False
            elif (val[0]=="4"):
                 mBuffer[7]=1
                 if(pulsating):
                    pulsatingMotor= 7  
                    pulsating=False  
        # third line
        if (l==2):
            if(len(val)>1):
                pulsating=True
            if(val[0]=="1"):
                mBuffer[8]=1
                if(pulsating):
                    pulsatingMotor= 8
                    pulsating=False
            elif (val[0]=="2"):
                 mBuffer[9]=1
                 if(pulsating):
                    pulsatingMotor= 9
                    pulsating=False
            elif (val[0]=="3"):
                 mBuffer[10]=1
                 if(pulsating):
                    pulsatingMotor= 10
                    pulsating=False
            elif (val[0]=="4"):
                 mBuffer[11]=1
                 if(pulsating):
                    pulsatingMotor= 11  
                    pulsating=False
        # FOURTH line
        if (l==3):
            if(len(val)>1):
                pulsating=True
            if(val[0]=="1"):
                mBuffer[12]=1
                if(pulsating):
                    pulsatingMotor= 12
                    pulsating=False
            elif (val[0]=="2"):
                 mBuffer[13]=1
                 if(pulsating):
                    pulsatingMotor= 13
                    pulsating=False
            elif (val[0]=="3"):
                 mBuffer[14]=1
                 if(pulsating):
                    pulsatingMotor= 14
                    pulsating=False
            elif (val[0]=="4"):
                 mBuffer[15]=1
                 if(pulsating):
                    pulsatingMotor= 15  
                    pulsating=False    
        l+=1



def set_intensity(line):
    global delayOff
    #line = 'i#'; 0<= # >= 9
    
    
    #change delay off if receive intensity level
    if(line[1]>='0' and line[1]<='3'):
        
            if line[1]== '0':
                delayOff = 0.05
            if line[1]== '1':
                delayOff = 0.004
            if line[1]== '2':
                delayOff = 0.001
            if line[1]== '3':
                delayOff = 0
           
           


    
def motor_cycle():
    global mBuffer
    global motors
    global delayOff
    global DELAY_ON
    global PULSE_DURATION
    global pulseTimer
    global pulsatingMotor
    global pulse

    if(pulseTimer>= PULSE_DURATION): #if we reached the pulse duration reset pulsation
        #toggle motor state
        
            if(pulse):
                pulse=False
            else:
                pulse = True
            pulseTimer=0
            
    #activate motors
    i=0
    for m in motors:
        m.value(mBuffer[i])#copy buffer value to motor pin
        i+=1

    #sleep
    sleep(DELAY_ON)
    if(pulsatingMotor>=0): #if there is a motor to pulsate
         if pulse==False:
             motors[pulsatingMotor].off()

    sleep(DELAY_ON)
    #deactivate motors
    clear_all()
    if(pulsatingMotor>=0): #if there is a motor to pulsate
         if pulse:
             motors[pulsatingMotor].on()
               
            

    #sleep
    sleep(delayOff)

    pulseTimer+= DELAY_ON+DELAY_ON+ delayOff

    


def check_buttons():
    """
    Button report event. "Bxs*"  x= button name (1,2,3,4,U,D,M,P,F), s= status (U= released or D= pressed ) 
    """
    buttonValues = [b1.value(),b2.value(),b3.value(),b4.value(),bUp.value(), bDown.value(),bMin.value(), bPlus.value(), bStar.value(), bNext.value()]
    buttonNames= ["1","2","3","4","U","D","M","P","F","N"]

   # flank detection for every button
    for i in range(10):
        if buttonValues[i] != interfaceButtons[i]:      #if value is not the same as buffer
            interfaceButtons[i] = buttonValues[i]       #change the state of buffer
            if buttonValues[i]:                         #button released = true
                    print("B"+buttonNames[i]+"U*")      #print button release report
            else:                                       #button pressed = false
                    print("B"+buttonNames[i]+"D*")      #print button press report
    
    

clear_all()

#
# instantiate second 'background' thread on RD2040 dual processor to monitor and buffer
# incomming data from 'stdin' over USB serial port using ‘bufferSTDIN‘ function (above)
#
bufferSTDINthread = start_new_thread(bufferSTDIN, ())


try:
    while True:
        buffLine = getLineBuffer()                      # get a line if it is available?
        if buffLine:                                    # if there is...
            #print ("<<"+buffLine + ">>")    
            if(buffLine[0]=="b"):                       # keep alive response           
               # led1.toggle()                           # toogle led
               #sleep(1)
               pass

            elif (buffLine[0]=="i"):                    # intensity value          
                set_intensity(buffLine)                 # parse intensity
            elif (buffLine[0]>="0" and buffLine[0]<="4"):                
                set_window(buffLine)               # refresh display
        
        motor_cycle()                                   # motor loop
        check_buttons()                                 # Poll button status
        keepAliveTimer+= delayOff+DELAY_ON              #keep a timer for sending keep alive signal
        if(keepAliveTimer>= KEEP_ALIVE_PERIOD):
            print("a*")                                     # keep alive signal
            keepAliveTimer=0
        
except KeyboardInterrupt:                               # trap Ctrl-C input
    clear_all()
    terminateThread = True                              # signal second 'background' thread to terminate 
    exit()

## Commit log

2025-02-26 Added hardware source files and bill of materials
    [FINAL_4x4matrix.FCStd, bill of materials.csv, btnCap1_correct_5mmbtn-Body.stl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]
2026-02-04 docs: Introduce and detail the TOMAT Light PWA smartphone alternative across the README, prototype description, design document, and use guide.
